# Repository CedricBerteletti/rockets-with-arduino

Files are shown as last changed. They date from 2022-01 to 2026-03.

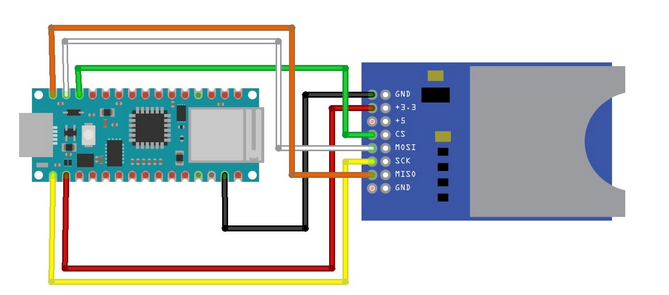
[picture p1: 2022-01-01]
electronique/arduino-sdcard.PNG

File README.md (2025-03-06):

# Fusée avec Arduino embarqué

Quelques programmes pour notre fusée avec Arduino embarqué !

## compte-a-rebours - Compte à rebours

Un compte à rebours simple de 10 secondes, verrouillé par une clé RFID et déclenchant un relais, pour l'allumage électrique d'une micro-fusée.
Basé sur un Arduino Nano.

Bibliothèques nécessaires :
- SPI
- MFRC522 V1.4 : contrôle de la clé RFID

## logiciel-vol - Logiciel de vol pour l'Arduino embarqué

Basé sur un Arduino Nano 33 IoT.

Bibliothèques nécessaires :
- Arduino_LSM6DS3 : centrale inertielle (CI)
- WiFiNINA : connexion et communication via Wifi
- SD : gestion de la carte SD
- Servo : gestion des servomoteurs
- avr/dtostrf : pour convertir les floats en chaîne de caractères

Permet de recevoir via Wifi les commandes (cf. exemple-script-fusee.rl) :
- Commandes générales et connexion :
    - *wifi.connectNetwork ssid pwd*: permet de se connecter au réseau wifi *ssid* avec le mot de passe *pwd*.
    - *wifi.broadcastUdpClient n ip_rocket port_rocket*: permet de connaître le client distant numéro n (de 0 à 4) et de lui retourner les mesures et le statut de la fusée.
    - *system.delay duree* : bloque l'exécution de la boucle principale de l'Arduino pendant *duree* ms.
- Loggers et différents états  :
    - *rocket.status* : état de la fusée.
    - *wifi.status* : état de la connexion Wifi.
    - *logger.status* : indique les différents loggers actifs.
	- *logger.log str* : écrit la chaîne quelconque str dans les logs. Possible d'utiliser des commandes au pré-processeur dans la chaîne (par exemple {{DATE}}).
    - *logger.initSdcard* : initialise et lance les logs sur la carte SD.
    - *logger.flushToSdcard* : force le vidage du cache des logs sur la carte SD.
	- *logger.sizeLogsFile* : taille du fichier de logs
	- *logger.clearLogsFile* : vider le fichier de logs
    - *logger.setSamplesLogImuData n* : indique le *n* nombre d'échantillons sautés pour les logs (via serial, SD-Card et Wifi) des données de la centrale inertielle. 0 => pas de log.
    - *logger.activateLogFlush* et *logger.deactivateLogFlush*: active/désactive les logs de vidage du cache sur la carte SD.
    - *logger.activateLogRocketStatus* et *logger.deactivateLogRocketStatus* : active/désactive les logs d'état général de la fusée.
	- *logger.activateLogToSerial* et *logger.deactivateLogToSerial*
	- *logger.activateLogToSd* et *logger.deactivateLogToSd*
	- *logger.activateLogToWifi* et *logger.deactivateLogToWifi*
- Plan/script de vol de la fusée :
    - *flightplan.configureStep no_step delai commande* : précise la temporisation (durée en ms) de l'étape *no_step* et la commande à exécuter au **début** de l'étape.
    - *flightplan.getSteps* : renvoie toutes les étapes de vol de la fusée.
    - *flightplan.goStep step* : permet de passer directement à l'étape *step* (et éventuellement de faire des boucles).
- Centrale inertielle :
    - *imu.getBuffer* : renvoie toutes les données inertielles contenues dans le buffer de calibration
    - *imu.calibrate ax ay az valpha vbeta vgamma* : intégre des offsets dans les données brutes des capteurs de façon à avoir exactement les valeurs passées en calibration
    - *imu.setMinAccelerationFilter mina" : paramètre l'accélération minimale à prendre en compte dans la centrale inertielle (les accélérations inférieures seront considérées comme nulles pour éviter la dérive)
    - *imu.setMinAngularVelocityFilter minv" : paramètre la vitesse angulaire minimale à prendre en compte dans la centrale inertielle (les accélérations inférieures seront considérées comme nulles pour éviter la dérive)
    - *imu.setRcsServoX n* : indique que le servo-moteur n servira pour le contrôle de l'axe X par la tuyère orientable
    - *imu.setRcsServoY n* : indique que le servo-moteur n servira pour le contrôle de l'axe Y par la tuyère orientable
    - *imu.setWcsServoX n* : indique que le servo-moteur n servira pour le contrôle de l'axe X par les ailerons
    - *imu.setWcsServoY n* : indique que le servo-moteur n servira pour le contrôle de l'axe Y par les ailerons
    - *imu.activateRcs* et *imu.deactivateRcs* : active et désactive la stabilisation par la tuyère orientable
    - *imu.activateWcs* et *imu.deactivateWcs* : active et désactive la stabilisation par les ailerons    - 
    - *imu.setCorrectionFunctionParameters a b c d*: Passage des paramètres d'un polynome de degré 3 (a.err³ + b.err² + c.err + d) donnant la correction à appliquer sur la position des servomoteurs en fonction de l'écart à la verticale.
- Lancement et actions générales :
    - *rocket.launch code* ou *flightplan.start code* : Lance l'exécution du plan de vol avec le lancement de l'étape 0. Protégé par un code.
    - *rocket.stage* : Sans effet. Permet de générer un log indiquant que l'on est passé à l'étage suivant de la fusée.
    - *flightplan.stop code* : interrompt le programme de la fusée et revient à l'étape initiale. Protégé par un code. Attention aux conséquences !
- Gestion des signaux sur les broches de l'Arduino :
    - *pin.setMode pin mode* : configure la broche n°*pin* (OUTPUT/INPUT). 
    - *pin.digitalWrite pin niveau* : envoie un signal (0 ou 1) ou l'arrête sur la sortie numérique *pin* désignée.
    - *pin.fire pin* : idem *pin.digitalWrite pin 1*.
    - *pin.tone pin freq* : joue un son de fréquence *freq* hz sur la sortie *pin*.
    - *pin.toneStop pin* : coupe le son sur la sortie *pin*.
- Gestion des servo-moteurs
    - *servo.setAngle servo angle* : positionne (mais sans correction/calibration) sur un *angle* précis (de 0 à 180°) le servo moteur n°*servo*.
    - *servo.setPosition servo position* : positionne le servo moteur n°*servo* sur une position repérée de -100 à 100 (en tenant compte de la calibration du servo).
    - *servo.setOffset servo offset* : indique un décalage du 0 pour le servo moteur n°*servo*
    - *servo.setSlope servo slope* : indique le coefficient entre angle et position pour le servo moteur n°*servo*
    - *servo.status servo* : indique le status pour le servo moteur n°*servo* (paramètres de calibration et consigne actuelle)

Remarques sur l'Arduino Nano 33 IoT :
- La gestion de l'USB est basé sur un programme chargé par le bootloader. Mais si le programme personnalisé est bogué, il peut empêcher la routine de gestion de l'USB de fonctionner. L'Arduino apparaît alors "briqué". Il faut appuyer rapidement 2 fois sur le boutons reset pour forcer le rechargement du bootloader (et la gestion du port USB).
- **Attention** : I/O en 3,3 V.

Remarques sur la carte SD :
- à alimenter en 5V ;
- nom de fichier de 8 caractères maximum (retour à l'époque du DOS !!)

Commandes lancées depuis un smartphone :
- Trouver l'adresse IP de la fusée :
```
ip neigh
```
- Connexion à la fusée (port 23900 par défaut) :
```
nc -u 192.168.x.x {port}
```
Il est ensuite possible de continuer à taper pour envoyer les commandes.
- Etat de la connexion :
```
netstat | grep {port}
```
- Envoi d'une commande :
```
echo -n "WB 0 192.168.0.3 23900" > /dev/udp/192.168.0.3/23900
```

## controle-sol - Centre de Contrôle et de Télémétrie

Application Python permettant de configurer le vol de la fusée, de vérifier son statut, de lancer le compte à rebours final et d'acquérir et d'afficher les infos de vol.

## Électronique

- Possibilité d'alimenter les servo-moteurs à une tension supérieure aux 5V de l'Arduino (par exemple avec les 7,4 V de la batterie), pour accélérer la vitesse de rotation.

### Arduino Nano 33 IoT

Ne pas utiliser les broches D10, D11, D12, D18 et D19 utilisées par défaut pour les interfaces SPI et I2C (sur laquelle est branchée notamment l'IMU).

#### LSM6DS3 intégré

The Arduino LSM6DS3 library allows us to use the Arduino Nano 33 IoT IMU module without having to go into complicated programming. The library takes care of the sensor initialization and sets its values as follows:
- Accelerometer range is set at -4 |+4 g with -/+0.122 mg resolution.
- Gyroscope range is set at -2000 | +2000 dps with +/-70 mdps resolution.
- Output data rate is fixed at 104 Hz.

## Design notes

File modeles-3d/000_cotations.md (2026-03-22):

## Quelques dimensions standards

- Diam engrenage 12 dents : 13.5 mm
- Diam engrenage 20 dents : 21.5 mm
- Diam engrenage 24 dents : 26 mm
- Diam engrenage 32 dents : 37.2 mm
- Entraxe Lego engrenage 12 dents - 12 dents : 12.5 mm
- Entraxe Lego engrenage 12 dents - 20 dents : 16.5 mm
- Entraxe Lego engrenage 12 dents - 20 dents : 18.75 mm
- Entraxe Lego engrenage 12 dents - 20 dents : 24.5 mm
- Engrenage Lego : module 1,0 mm
- Engrenage Servo MG90 / SG90 / AD002 : module 0,20 mm ; 24 dents

## Inserts M2 / M2.5 / M3

Diamètre trou pour insert M2 : 3,2 mm
Diamètre trou pour vis M2 : 2,0 mm
Diamètre trou pour insert M3 : 4,0 mm
Diamètre trou pour vis M3 : 3,0 mm

## Dimensionnement des parachutes

- 125 cm : 600 - 1400 g
- 90 cm : 400 - 600 g
- 70cm : 300 - 400 g
- 55 cm : 200 - 300 g
- 45 cm : 100 - 200 g
- 35 cm : 50 - 100 g

# Fusée étage 2 seul

## Base

Hauteur : 185 mm
Masse sans moteur : 180 g
Centre de gavrité (depuis bas) : 80 mm

## Corps

Hauteur : 585 mm
Masse : 146 g
Centre de gavrité (depuis bas) : 315 mm

## Base + Corps

Hauteur : 770 mm
Masse sans moteur : 326 g
Centre de gavrité (depuis bas) : 275 mm

## Coiffe

Hauteur : 210 mm
Masse sans batterie : 228 g
Centre de gavrité (depuis bas) : 65 mm
Masse batterie Black Lithium 45 C 7,4V 300mAh : 16 g

## Caméra

Environ 1 Go pour 4 min d'enregistrement

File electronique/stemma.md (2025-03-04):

STEMMA 4-Pin I2C (both standard & STEMMA QT)

This connector is for I2C devices and has a 4 pin connector

For JST PH (2mm pitch) the pin order is

    Green for SCL
    White for SDA
    Red for V+
    Black for GND

For the STEMMA QT cables, we follow the Qwiic convention:

    Black for GND
    Red for V+
    Blue for SDA
    Yellow for SCL

Note the colors are slightly different for SDA/SCL but the pin order is the same

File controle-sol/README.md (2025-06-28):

# Logiciel de contrôle au sol

## Description

## Lancement

### Windows
Au besoin, créer le Python virtual environment and installer les différents packages.
```
python.exe -m pip install --upgrade pip
python -m venv .venv
.\.venv\Scripts\activate
pip install PyQt6
pip install pyqtgraph
pip install PyOpenGL
pip install numpy-stl
```

Activer le Python virtual environment
```
.\.venv\Scripts\activate
```

Lancement
```
python main.py
```

### Linux
Au besoin, créer le Python virtual environment and installer les différents packages.
```
python3 -m venv .venv
source .venv/bin/activate
pip3 install PyQt6
pip3 install pyqtgraph
pip3 install PyOpenGL
pip3 install numpy-stl
```

Activer le Python virtual environment
```
source .venv/bin/activate
```

Lancement
```
python3 main.py
```

## TODO

- EcranPrincipal : signals pour le bouton Connecter !
- EcranPrincipal : signals pour les boutons Lancer et Stop ! Ouvrir une boîte de dialogue pour le mot de passe (précharger avec self.password).
- EcranPrincipal : Ajouter splitter entre les deux groupes de widgets graphiques du panneau droit
- EcranPrincipal : toggle de défilement auto pour les logs généraux du panneau gauche (cf. panneau droit)
- CentraleInertielle : intégrations vitesses et positions (en supposant le référentiel galiléen pour l'instant)
- Orienter la vue 3D en fonction de l'orientation réelle de la fusée
- Instructions RFP supplémentaires destinées au centre de contrôle pour indiquer les fichiers 3D lors des différents étages.

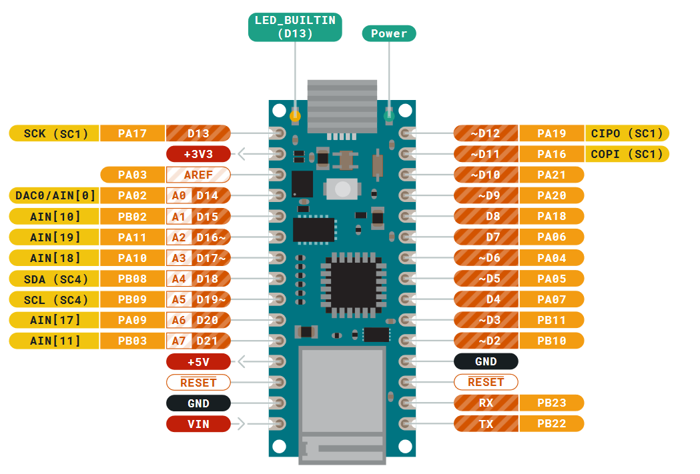
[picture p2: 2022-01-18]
electronique/arduino-pins2-correct-numero-pin.PNG

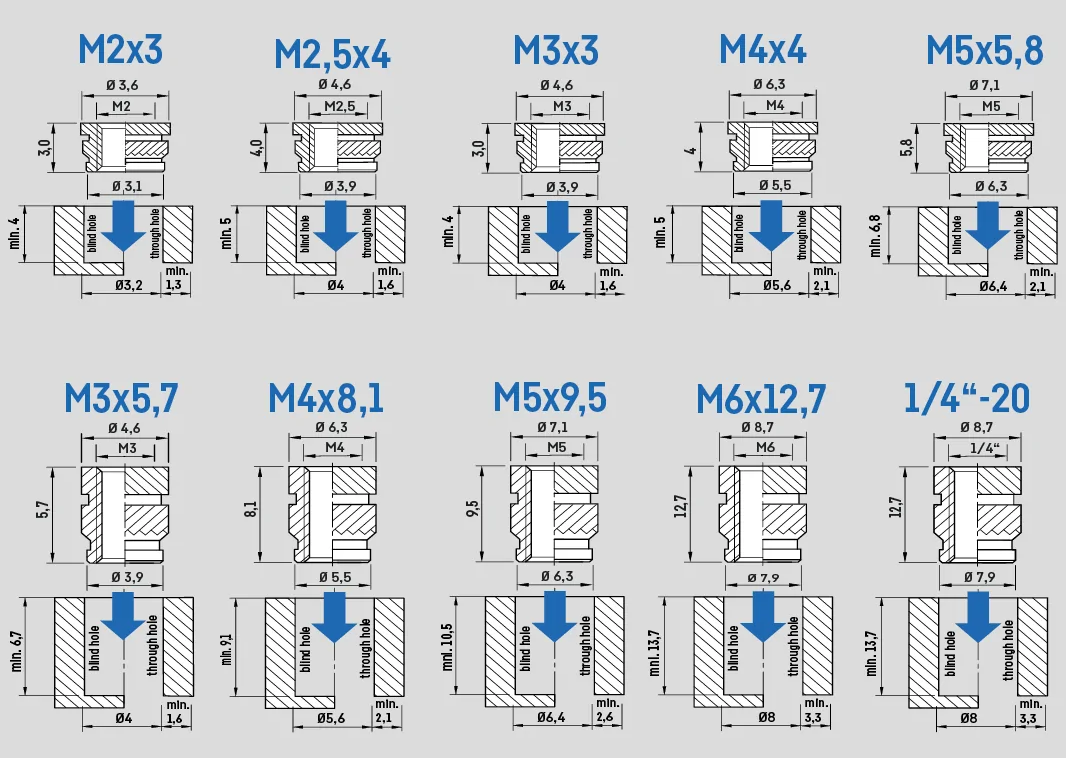
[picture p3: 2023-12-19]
modeles-3d/000_cotations_inserts.png

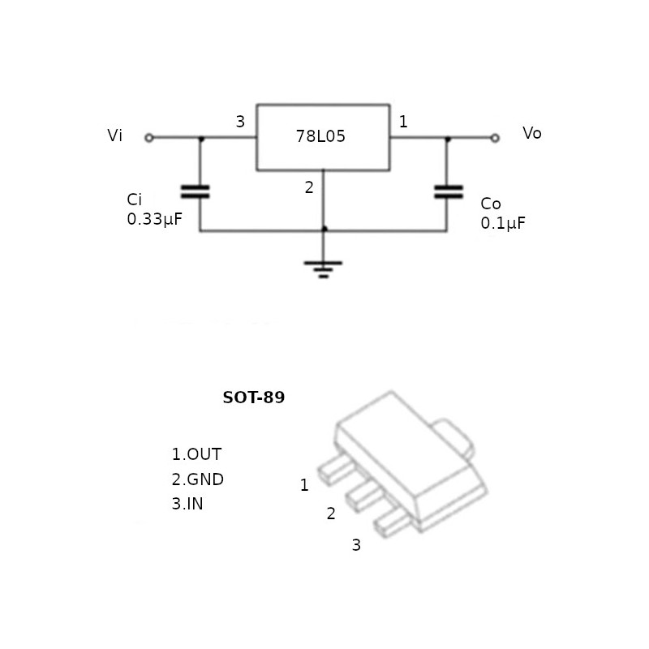
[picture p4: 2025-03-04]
electronique/regulateur-de-tension-5v-avec-perte-7805.jpg

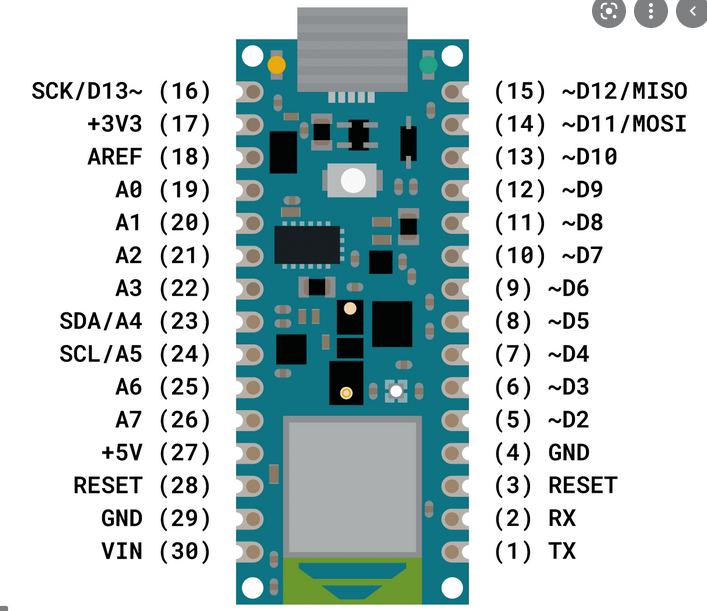
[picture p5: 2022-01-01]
electronique/arduino-pins.PNG

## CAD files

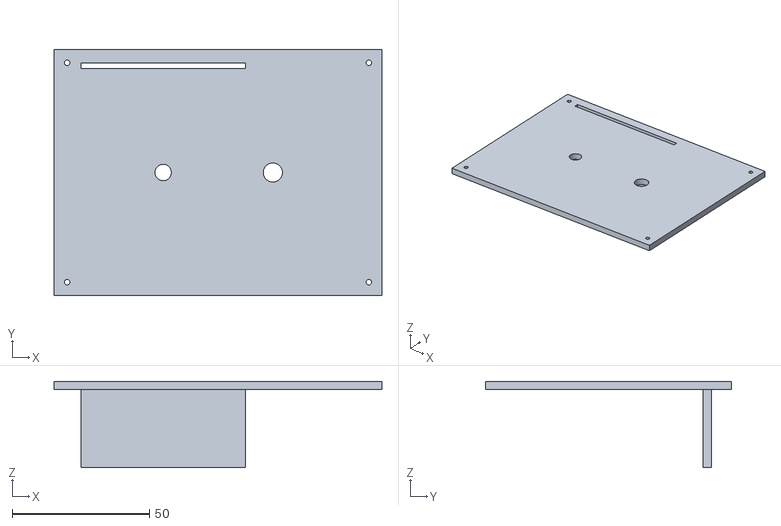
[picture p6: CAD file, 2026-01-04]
compte-a-rebours/modeles-3d/couvercle.stl
119.6 x 89.6 x 31.5

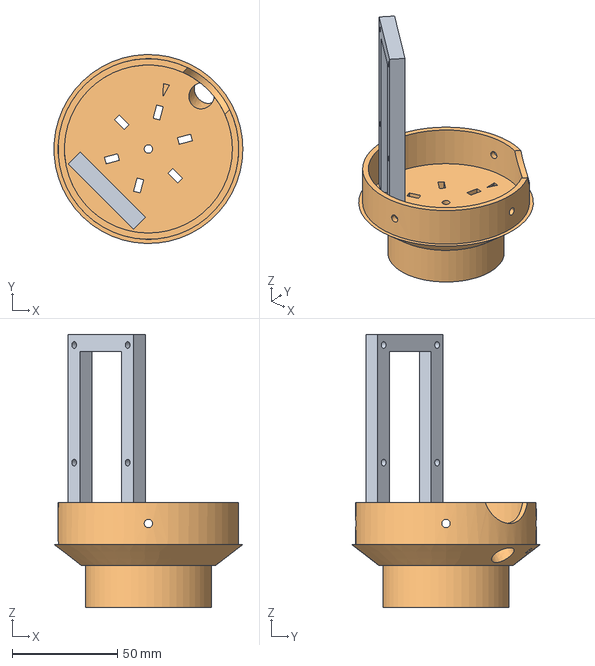
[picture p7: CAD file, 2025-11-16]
modeles-3d/250_etage2b_base_coiffe.FCStd
89.9 x 90.0 x 130.0 mm
Support Arduino
Corps

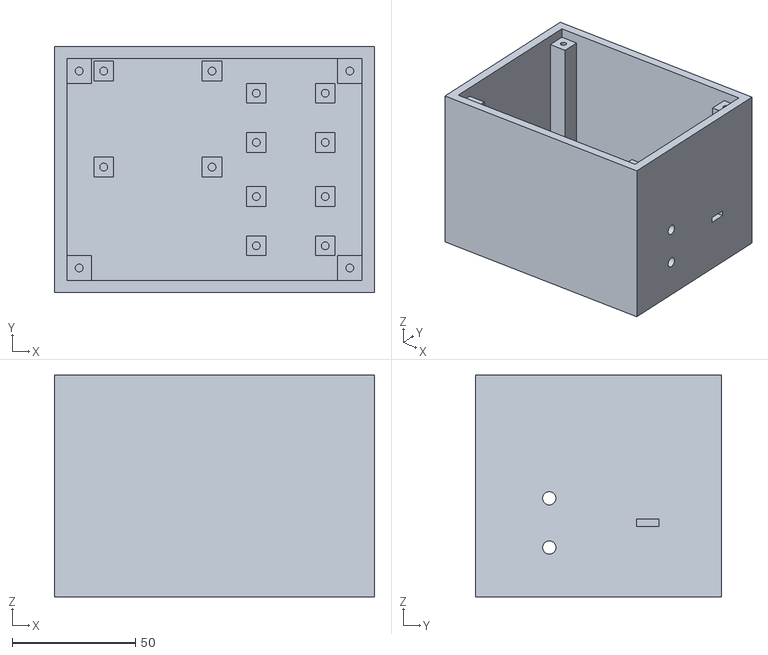
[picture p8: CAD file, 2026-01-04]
compte-a-rebours/modeles-3d/boitier.stl
130.0 x 100.0 x 90.0

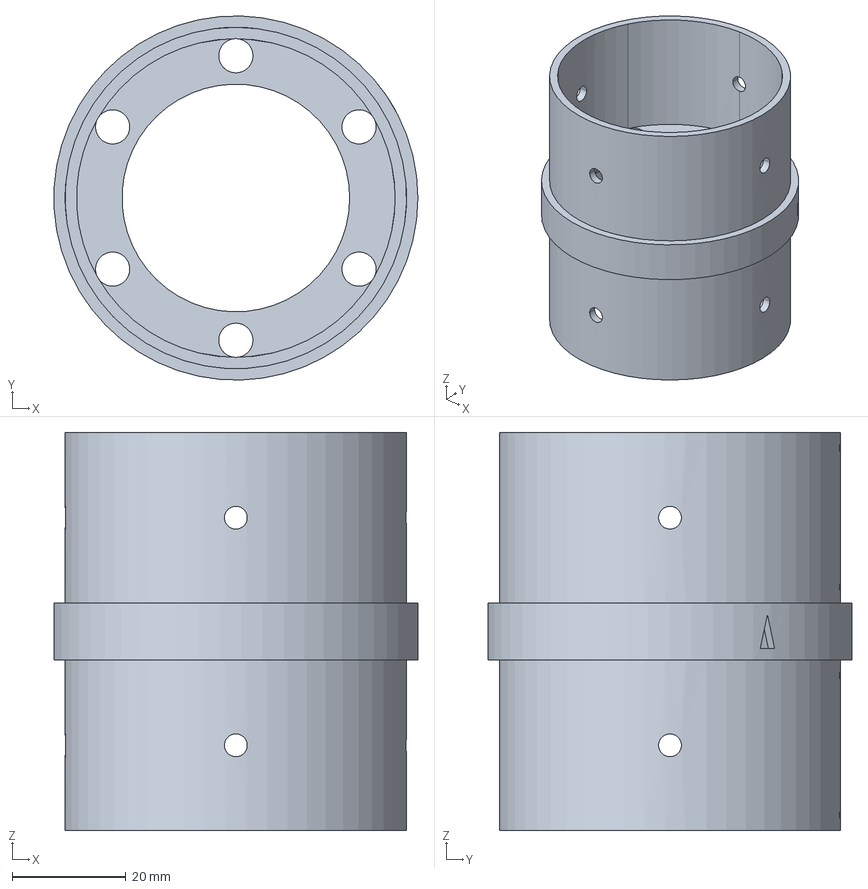
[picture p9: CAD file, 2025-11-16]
modeles-3d/210_etage2_liaison.FCStd
63.9 x 64.0 x 70.0 mm

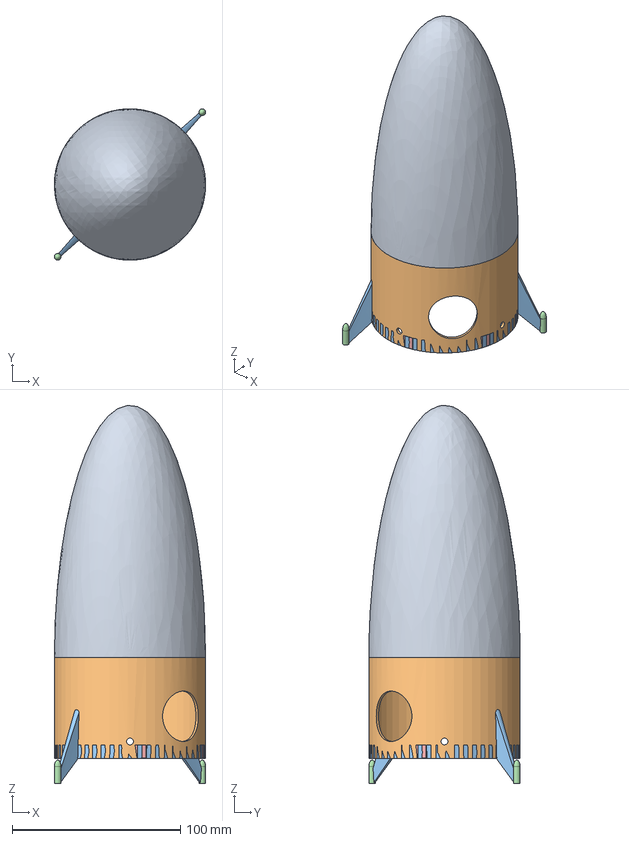
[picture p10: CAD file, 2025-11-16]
modeles-3d/251_etage2b_coiffe.FCStd
90.0 x 90.0 x 224.9 mm
Coiffe
Corps
Ailerons
Corps001
Tube porte ailerons

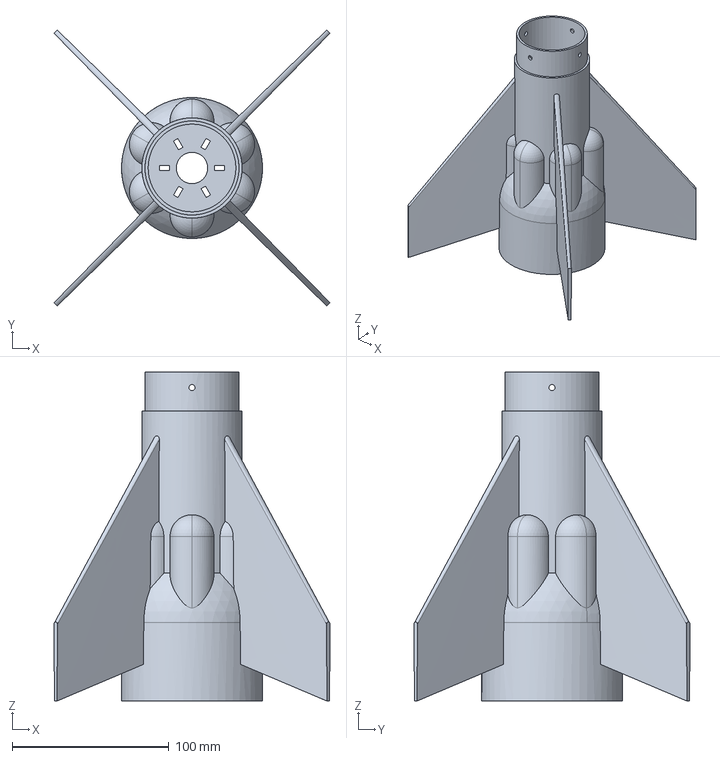
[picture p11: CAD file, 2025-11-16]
modeles-3d/200_etage2_base.FCStd
176.1 x 176.1 x 210.0 mm

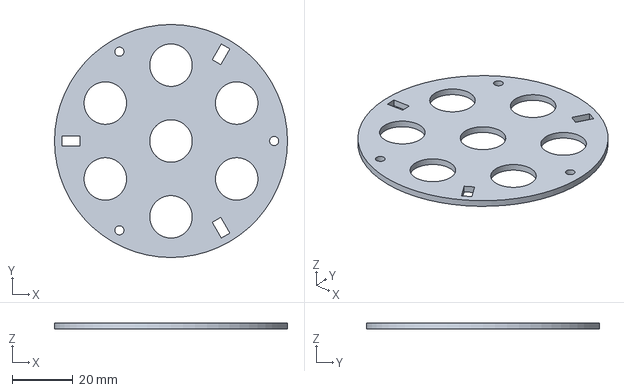
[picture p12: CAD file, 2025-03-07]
modeles-3d/701_moteur_berceau_7_couvercle.FCStd
76.8 x 76.8 x 2.00 mm

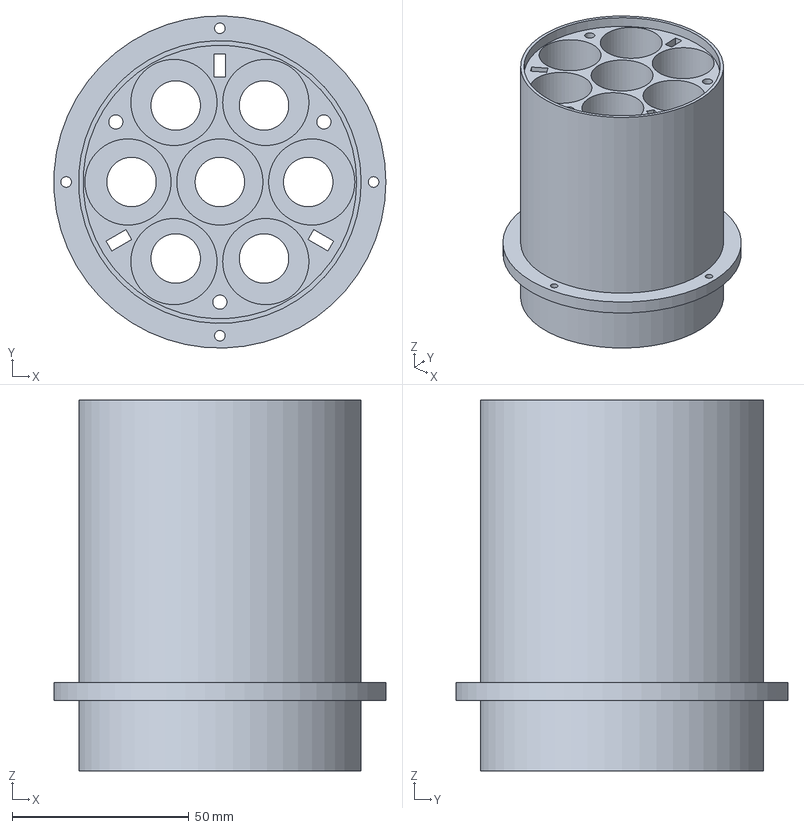
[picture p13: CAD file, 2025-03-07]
modeles-3d/700_moteur_berceau_7.FCStd
93.9 x 94.0 x 105.0 mm

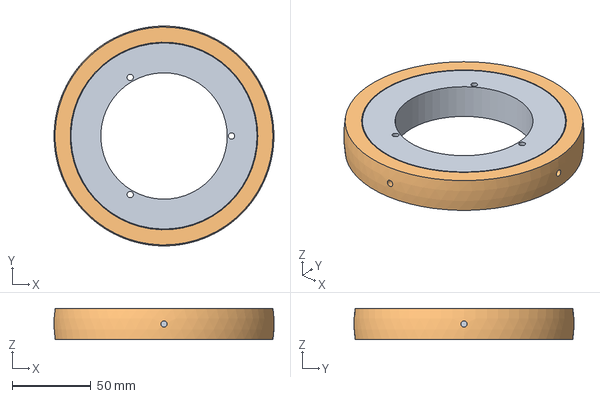
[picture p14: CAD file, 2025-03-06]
modeles-3d/720_orientation_moteurs_sphere.FCStd
139.9 x 139.9 x 20.0 mm
Corps001
Corps

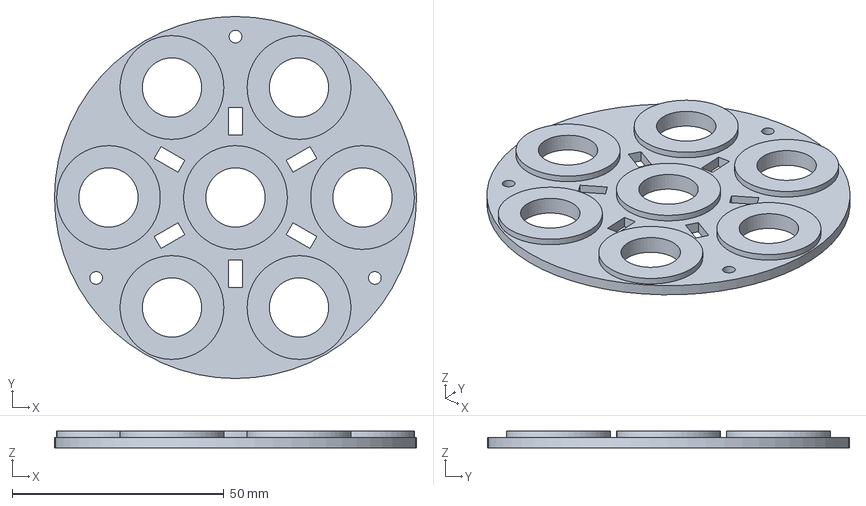
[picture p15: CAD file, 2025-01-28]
modeles-3d/201_etage2_couvercle_base.FCStd
85.5 x 85.5 x 4.00 mm

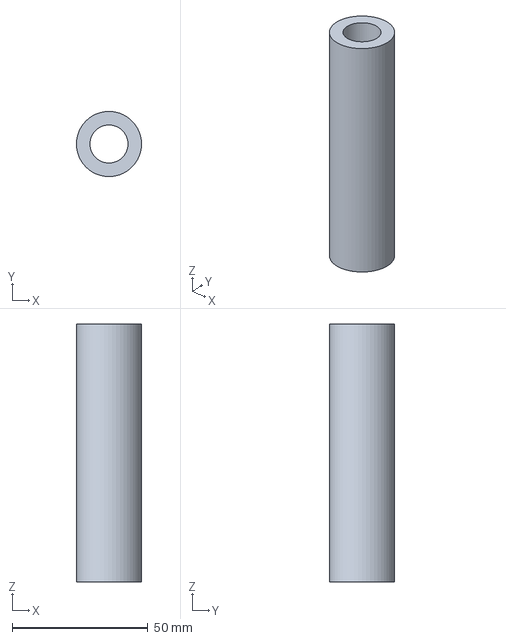
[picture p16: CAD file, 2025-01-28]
modeles-3d/710_adaptateur_moteur_24_95_vers_18_70.FCStd
24.0 x 24.0 x 95.0 mm

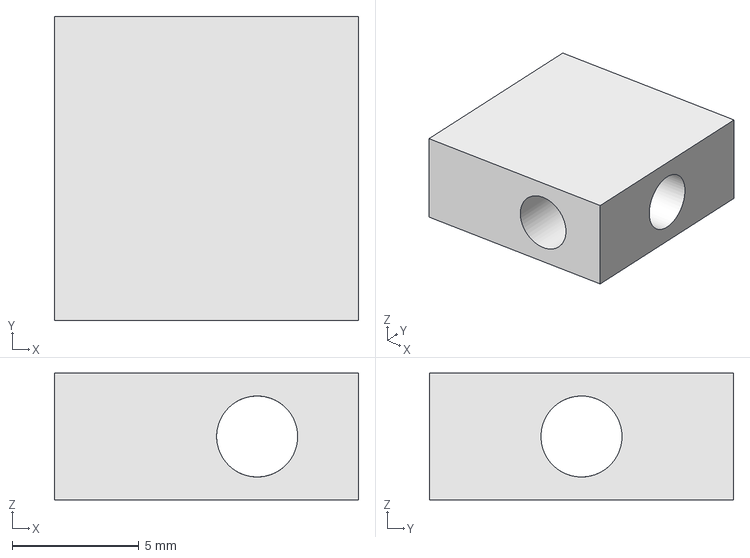
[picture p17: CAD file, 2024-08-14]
modeles-3d/902_servo_fixation.FCStd
12.0 x 12.0 x 5.00 mm

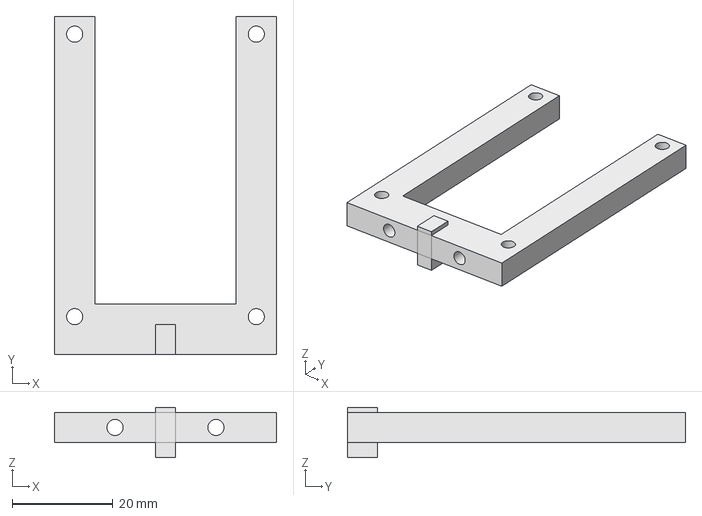
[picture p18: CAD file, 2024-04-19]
modeles-3d/301_capsule_support_arduino.FCStd
44.0 x 67.0 x 10.0 mm

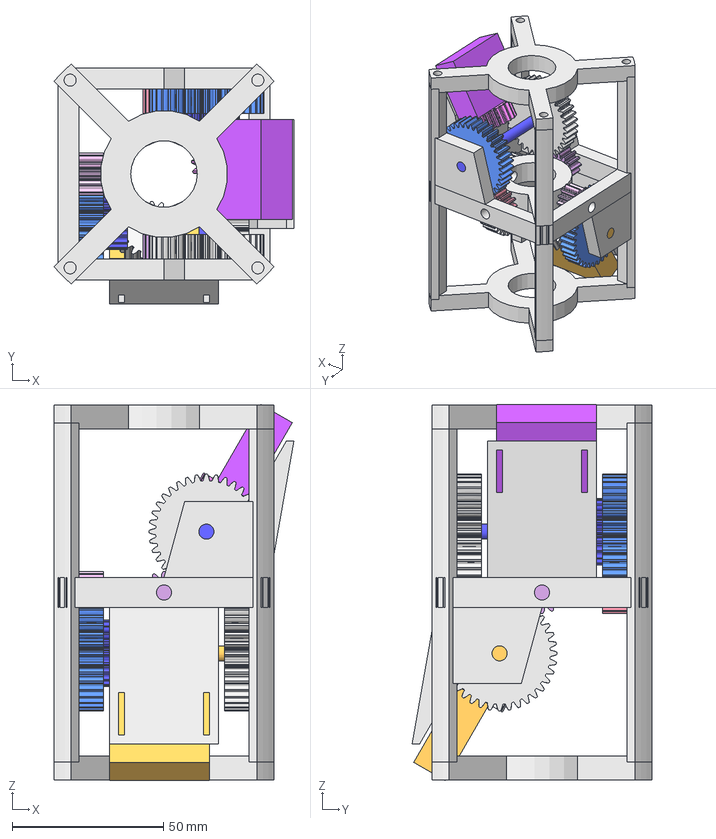
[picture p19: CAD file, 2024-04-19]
modeles-3d/300_capsule_support_engrenages_ailerons.FCStd
79.2 x 79.2 x 124.2 mm
Cadre extérieur
Montant1
Montant2
Montant3
Montant4
Support d'axes 1
Support d'axes 2
Support d'axes 3
Support d'axes 4
Support servo 1
Support servo 2
Cadre intérieur
Guide tube moteur 1
Guide tube moteur 2
EngrenageA1
EngrenageB1
Axe AB1
EngrenageA2
EngrenageB2
EngrenageA3
Servo
EngrenageA4
EngrenageA005
EngrenageB003
EngrenageA006
EngrenageB004
EngrenageA007
Axe AB002
EngrenageA008
Servo002
EngrenageA009

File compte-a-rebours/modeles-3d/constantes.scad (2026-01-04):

hauteur = 90;
longueur = 130;
largeur = 100;
epaisseur = 5;
jeu = 0.2;

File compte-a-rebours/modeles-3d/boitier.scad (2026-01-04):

use <commun.scad>

include <constantes.scad>

module boitier() {
    union() {
        // Boitier externe
        difference() {
            cube([longueur, largeur, hauteur], center = true);
            union() {
                translate ([0, 0, epaisseur]) cube([longueur-2*epaisseur, largeur-2*epaisseur, hauteur-epaisseur], center = true);
                
                // Trous douilles
                translate([0, -largeur/5, -hauteur/2+20])
                rotate([0, 90, 0])
                cylinder(h=longueur+jeu, r1=2.5+jeu, r2=2.5+jeu, center=true, $fn=30);
                translate([0, -largeur/5, -hauteur/2+40])
                rotate([0, 90, 0])
                cylinder(h=longueur+jeu, r1=2.5+jeu, r2=2.5+jeu, center=true, $fn=30);
                
                
                translate([longueur/2, largeur/5, -hauteur/6])
                cube([longueur/2+jeu, 9, 3], center=true);
            }
        }
        
        // Fixation couvercle
        translate ([longueur/2-2*epaisseur, largeur/2-2*epaisseur, 0]) fixation_couvercle();
        translate ([-longueur/2+2*epaisseur, largeur/2-2*epaisseur, 0]) fixation_couvercle();
        translate ([longueur/2-2*epaisseur, -largeur/2+2*epaisseur, 0]) fixation_couvercle();
        translate ([-longueur/2+2*epaisseur, -largeur/2+2*epaisseur, 0]) fixation_couvercle();
        
        // Support circuit imprimé
        translate([-longueur/2+44/2+epaisseur+18, largeur/2-39/2-epaisseur-8, -hauteur/2+epaisseur+4]) pieds_support_rect(44, 39, 10, 8);
        
        relai_trans_x = longueur/2-28/2-epaisseur-15;
        relai_trans_y = largeur/2-20/2-epaisseur-14;
        relai_trans_z = -hauteur/2+epaisseur+15;
        // Relai commande fusée
        translate([relai_trans_x, relai_trans_y, relai_trans_z]) relai_arduino_support(30);
        
        // Relai commande allumage
        translate([relai_trans_x, -relai_trans_y, relai_trans_z+10]) relai_arduino_support(50);
        
        // Relai puissance allumage
    }
}

module fixation_couvercle() {
    difference () {
        translate ([0, 0, -epaisseur/2-jeu/2]) cube([2*epaisseur, 2*epaisseur, hauteur-epaisseur-jeu], center = true);
        translate ([0, 0, hauteur/2-10]) m2_trou_insert();
    }
}

boitier();

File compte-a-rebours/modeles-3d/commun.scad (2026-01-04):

jeu = 0.2;

module m2_trou_vis(hauteur=10) {
    cylinder(h=hauteur, r1=1, r2=1, center=true, $fn=30);
}

module m2_trou_insert(hauteur=10) {
    cylinder(h=hauteur, r1=1.6, r2=1.6, center=true, $fn=30);
}

module m3_trou_vis(hauteur=10) {
    cylinder(h=hauteur, r1=1.5, r2=1.5, center=true, $fn=30);
}

module m3_trou_insert(hauteur=10) {
    cylinder(h=hauteur, r1=2, r2=2, center=true, $fn=30);
}

module relai_arduino_support(hauteur=10) {
    pieds_support_rect(28, 20, hauteur, 8);
}

module pieds_support_rect(longueur=28, largeur=20, hauteur=10, profondeur_trou=10) {
    // La longueur et la largeur correspondent aux entre-axes des trous
    // de fixation
    translate([-longueur/2, -largeur/2, 0]) pied(hauteur, profondeur_trou);
    translate([-longueur/2, largeur/2, 0]) pied(hauteur, profondeur_trou);
    translate([longueur/2, -largeur/2, 0]) pied(hauteur, profondeur_trou);
    translate([longueur/2, largeur/2, 0]) pied(hauteur, profondeur_trou);
}

module pied(hauteur=10, profondeur_trou = 10) {
    difference() {
        cube([8, 8, hauteur], center=true);
        translate([0, 0, (hauteur-profondeur_trou)/2]) m2_trou_insert(profondeur_trou+jeu);
    }
}

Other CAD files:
modeles-3d/900_axe_5_mm.FCStd
modeles-3d/302_capsule_aileron.FCStd
modeles-3d/901_servo_engrenage.FCStd
compte-a-rebours/modeles-3d/couvercle.scad
compte-a-rebours/modeles-3d/ensemble.scad
modeles-3d/201_etage2_couvercle_base.stl
modeles-3d/210_etage2_liaison.3mf
modeles-3d/210_etage2_liaison.stl
modeles-3d/250_etage2b_base_coiffe.stl
modeles-3d/251_etage2b_coiffe.stl
modeles-3d/300_capsule_support_engrenages_ailerons.stl
modeles-3d/301_capsule_support_arduino.stl
modeles-3d/302_capsule_aileron.stl
modeles-3d/700_moteur_berceau_7.stl
modeles-3d/701_moteur_berceau_7_couvercle.stl
modeles-3d/710_adaptateur_moteur_24_95_vers_18_70.stl
modeles-3d/720_orientation_moteurs_sphere.stl
modeles-3d/900_axe_5_mm.stl
modeles-3d/901_servo_engrenage.stl
modeles-3d/902_servo_fixation.stl

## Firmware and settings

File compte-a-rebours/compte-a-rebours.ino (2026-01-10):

/*
 * --------------------------------------------------------------------------------------------------------------------
 * Compte à rebours pour l'allumage d'une fusée. Verrouillé par une clé RFID.
 * --------------------------------------------------------------------------------------------------------------------
 * @author Cédric Berteletti
 */

#include <SPI.h>
#include <MFRC522.h>

#define RST_PIN       9     // Configurable, see typical pin layout above
#define SS_PIN        10    // Configurable, see typical pin layout above

#define SEUIL_BOUTON  255
#define ROCKET_PIN    20    // Broche à laquelle est reliée le câble de signal de la fusée contrôlant la mise-à-feu
#define BOUTON_PIN    21    // Broche à laquelle est relié le bouton de lancement

#define COMMANDE_PIN  2     // Broche de commande du relai de mise à feu

// Broches pour la LED RVB
#define ROUGE_PIN     16
#define VERT_PIN      17
#define BLEU_PIN      19


MFRC522 mfrc522(SS_PIN, RST_PIN);   // Création de l'instance pour la gestion de la clé RFID


MFRC522::MIFARE_Key cleRfid;

void setup() {
  Serial.begin(9600);  // Initialisation du port série pour la communication avec le PC
  while (!Serial);     // Ne rien faire si le port série n'est pas ouvert (pour Arduinos basé ATMEGA32U4)
  SPI.begin();         // Initialisation du bus SPI (auquel est relié la carte de lecture RFID)
  mfrc522.PCD_Init();  // Initialisation de la carte de lecture RFID MFRC522
  
  // Prepare key - all keys are set to FFFFFFFFFFFFh at chip delivery from the factory.
  for (byte i = 0; i < 6; i++) {
    cleRfid.keyByte[i] = 0xFF;
  }
  pinMode(ROCKET_PIN, INPUT);
  pinMode(BOUTON_PIN, INPUT);

  pinMode(ROUGE_PIN, OUTPUT);
  pinMode(VERT_PIN, OUTPUT);
  pinMode(BLEU_PIN, OUTPUT);
  analogWrite(ROUGE_PIN, 0);
  analogWrite(VERT_PIN, 0);
  analogWrite(BLEU_PIN, 255);

  pinMode(COMMANDE_PIN, OUTPUT);

  Serial.println(F("Console de lancement en attente ..."));
}

const int STATUT_VERROUILLE = 0;
const int STATUT_DEVERROUILLE = 1;
const int STATUT_COMPTE_A_REBOURS = 2;
const int STATUT_ALLUMAGE = 3;
int statut = STATUT_VERROUILLE;

// Durées en ms
const int DUREE_ALLUMAGE = 4000;
const int DELAI_LECTURE = 100;

const int NB_SECONDES_COMPTE_A_REBOURS_MANUEL = 10;

int intensiteRouge;
int intensiteVert;
int intensiteBleu;


static const char CLE_AUTORISEE[] = "C0 CE 41 25";

// But of course this is a more proper approach
void loop() {
  intensiteRouge = 0;
  intensiteVert = 0;
  intensiteBleu = 0;
  
  if(statut == STATUT_VERROUILLE) {
    intensiteBleu = 255;
    analogWrite(ROUGE_PIN, intensiteRouge);
    analogWrite(VERT_PIN, intensiteVert);
    analogWrite(BLEU_PIN, intensiteBleu);

    // VERIFICATION DE LA CLE RFID
    // Look for new cards, and select one if present
    if ( ! mfrc522.PICC_IsNewCardPresent() || ! mfrc522.PICC_ReadCardSerial() ) {
      delay(50);
      return;
    }  
    // Now a card is selected. The UID and SAK is in mfrc522.uid.
    
    if(verificationCle()) {
      Serial.println("Déverrouillage de la séquence de lancement.");
      statut = STATUT_DEVERROUILLE;

      intensiteVert = 255;
      intensiteBleu = 0;
      
      analogWrite(ROUGE_PIN, intensiteRouge);
      analogWrite(VERT_PIN, intensiteVert);
      analogWrite(BLEU_PIN, intensiteBleu);
    }
    else {    
      Serial.println("ALERTE ! Accès non autorisé !");
            
      intensiteBleu = 0;
      analogWrite(VERT_PIN, intensiteVert);
      analogWrite(BLEU_PIN, intensiteBleu);
      intensiteRouge = 255;
      analogWrite(ROUGE_PIN, intensiteRouge);
      delay(200);
      analogWrite(ROUGE_PIN, 0);
      delay(200);
      analogWrite(ROUGE_PIN, intensiteRouge);
      delay(200);
      analogWrite(ROUGE_PIN, 0);
      delay(200);
      analogWrite(ROUGE_PIN, intensiteRouge);
      delay(200);
      analogWrite(ROUGE_PIN, 0);
    }
  }

  else if(statut == STATUT_DEVERROUILLE && analogRead(BOUTON_PIN) >= SEUIL_BOUTON) {
    Serial.println("Séquence finale");
    statut = STATUT_COMPTE_A_REBOURS;
  }
  else if (statut == STATUT_DEVERROUILLE && analogRead(ROCKET_PIN) >= SEUIL_BOUTON) {
    Serial.println("signal fusée");
    statut = STATUT_ALLUMAGE;
  }
  
  else if (statut == STATUT_COMPTE_A_REBOURS) {

    intensiteVert = 0;
    intensiteVert = 40;
    intensiteRouge = 225;

    bool annulation = false;
    int delai = NB_SECONDES_COMPTE_A_REBOURS_MANUEL; // Compte à rebours en secondes
    while (delai > 0 && !annulation)
    {
      Serial.println(delai);
      analogWrite(ROUGE_PIN, intensiteRouge);
      analogWrite(VERT_PIN, intensiteVert);
      analogWrite(BLEU_PIN, intensiteBleu);
      delay(500);
      analogWrite(ROUGE_PIN, 0);
      analogWrite(VERT_PIN, 0);
      delay(500);

      annulation = analogRead(BOUTON_PIN) >= SEUIL_BOUTON;
      delai--;
    }
    
    if(annulation) {
      Serial.println("Annulation du lancement !");
      statut = STATUT_VERROUILLE;
    }
    else {
      intensiteVert = 0;
      intensiteRouge = 255;
      analogWrite(ROUGE_PIN, intensiteRouge);
      analogWrite(VERT_PIN, intensiteVert);
      analogWrite(BLEU_PIN, intensiteBleu);
      delay(800);
      analogWrite(ROUGE_PIN, 0);
      analogWrite(VERT_PIN, 0);
      delay(200);
      statut = STATUT_ALLUMAGE;
    }
  }
  else if (statut == STATUT_ALLUMAGE) {    
    Serial.println("Décollage !");
    // Mise à feu
    intensiteVert = 0;
    intensiteRouge = 255;
    analogWrite(ROUGE_PIN, intensiteRouge);
    analogWrite(VERT_PIN, intensiteVert);
    analogWrite(BLEU_PIN, intensiteBleu);
    digitalWrite(COMMANDE_PIN, HIGH);
    
    delay(DUREE_ALLUMAGE);
    
    digitalWrite(COMMANDE_PIN, LOW);
    analogWrite(ROUGE_PIN, 0);
    analogWrite(VERT_PIN, 0);
    analogWrite(BLEU_PIN, 0);
    statut = STATUT_VERROUILLE;
  }
  
  delay(DELAI_LECTURE);
}

boolean verificationCle() {
  char cleRfid[20] = "";
  char* pointeurCle = cleRfid;
  char* finBuffer = cleRfid + sizeof(cleRfid);
  for (byte i = 0; i < mfrc522.uid.size; i++) {
      if (pointeurCle + 3 < finBuffer)
      {
          if (i > 0)
          {
              pointeurCle += sprintf(pointeurCle, " ");
          }
          pointeurCle += sprintf(pointeurCle, "%02X", mfrc522.uid.uidByte[i]);
      }
  }
  Serial.print(F("Clé UID:"));
  Serial.print(cleRfid);
  Serial.println();

  if(strcmp(cleRfid, CLE_AUTORISEE) == 0) {
    return true;
  }
  else {    
    return false;
  }
}

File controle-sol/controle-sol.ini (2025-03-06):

[DEFAULT]
logging.level = INFO
theme.main = Fusion

delay.between_commands_ms = 50  # ms

telemetry.debug = false
telemetry.ip = 192.168.0.50
telemetry.port = 23900
telemetry.refresh_delay_ms = 10  # ms
telemetry.integration = true

imu.filters.angular_velocity_min = 1 # en ° par seconde
imu.filters.acceleration_min = 0.1 # en g (gravité terrestre 9.8 m/s²)

graphs.debug = false
graphs.refresh_delay_ms = 100  # ms

visu3d.grid_size = 400
visu3d.camera_distance = 500

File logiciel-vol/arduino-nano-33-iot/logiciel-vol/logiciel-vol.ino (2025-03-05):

/* 
 * --------------------------------------------------------------------------
 * Module principal du programme de vol d'une fusée
 * embarquant un Arduino Nano 33 IoT
 * --------------------------------------------------------------------------
 * @author Cédric Berteletti
 */

#include "constants.h"
#include "aides.hpp"
#include "Logger.hpp"
#include "Wifi.hpp"
#include "CentraleInertielle.hpp"
#include "Servomoteur.hpp"
#include "Interpreteur.hpp"


/* Modules */

// Instanciation d'un loggeur
Logger logger;

// Instanciation d'un objet gérant la connexion et les communications wifi
Wifi wifi;

// Instanciation de l'objet gérant la centrale inertielle (constructeur nécessitant un logger en paramètre)
CentraleInertielle centrale(logger);

// Servomoteurs des ailerons et de la tuyère sur les broches 18 à 21
Servomoteur servos[NB_SERVOS] = {Servomoteur(logger), Servomoteur(logger), Servomoteur(logger), Servomoteur(logger)};
int servosBroches[NB_SERVOS] = {SERVO0_PIN, SERVO1_PIN, SERVO2_PIN, SERVO3_PIN};

/* Programme de vol */
ProgrammeVol programmeVol(logger);

// Instanciation de l'interpréteur de commandes
Interpreteur interpreteur(logger, wifi, centrale, programmeVol, servos);


/* Variable globales */
// Date à laquelle réaliser un nouveau flush des données de logs
// (pas à chaque écriture car prend trop de temps)
long dateFlushSuivant = 0;
// Date à laquelle mettre à jour le statut de la fusée
long dateStatutSuivant = 0;
// Date à laquelle MAJ les données inertielles
long dateLectureImuSuivante = 0;
// Date à laquelle vérifier la présence de nouvelles commandes
long dateLectureCommandeSuivante = 0;
// Chaîne de caractères pour les logs
char strLog[LONGUEUR_MAX_CHAINE_CARACTERES];


/* Initialisation générale de la fusée */
void setup() {
  logger.log(MODULE_SYSTEME, "SYSTEM_INIT", "Initialisation générale");
  initSerie();
  delay(1000);

  logger.initCarteSd();
  
  wifi.listerReseaux();
  wifi.connecter();
  wifi.logStatut();

  logger.wifi = &wifi;
  logger.logUdpActif = true;

  // Pour éviter de polluer les logs, on désactive les logs des données inertielles avant le lancement
  centrale.samplesByDataLog = 0;
  centrale.init();

  // Initialisation des valeurs par défaut de calibration des servo-moteurs
  for(int i=0; i<NB_SERVOS; i++) {
    servos[i].init(i, servosBroches[i]);
  }

  programmeVol.init(millis());
  dateFlushSuivant = programmeVol.dateCourante;
  dateLectureCommandeSuivante = programmeVol.dateCourante;
}


// Boucle principale : lecture des capteurs ou des commandes et actions
void loop() {
  programmeVol.dateCourante = millis();

  // Actions à fréquence réduite (pas effectuées à chaque itération de loop())

  if(programmeVol.dateCourante > dateLectureImuSuivante) {
    centrale.lire();
    centrale.stabiliser();
    dateLectureImuSuivante = programmeVol.dateCourante + DELAI_IMU;
  }

  if(programmeVol.dateCourante > dateLectureCommandeSuivante) {
    interpreteur.lireCommande();
    dateLectureCommandeSuivante = programmeVol.dateCourante + DELAI_COMMANDE;
  }
  
  if(programmeVol.loggingStatutFusee && programmeVol.dateCourante > dateStatutSuivant) {
    programmeVol.logStatutFusee();
    dateStatutSuivant = programmeVol.dateCourante + DELAI_STATUT;
  }
  
  if(programmeVol.dateCourante > dateFlushSuivant) {
    logger.forcerEcritureSurCarteSd();
    dateFlushSuivant = programmeVol.dateCourante + DELAI_FLUSH;
  }

  if(programmeVol.evaluerEtapeSuivante()) {
    interpreteur.verifierEtExecuterCommande(programmeVol.getCommandeCourante());
  }
}

/* Initialisation de la liaison série (pour débogage sur un PC) */
void initSerie() {
  Serial.begin(115200);
  logger.log(MODULE_SYSTEME, "SERIAL_INIT", "Liaison série initialisée");
}

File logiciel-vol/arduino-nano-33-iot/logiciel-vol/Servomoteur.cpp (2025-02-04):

/*
 * --------------------------------------------------------------------------
 * Gestion d'un servomoteur
 * --------------------------------------------------------------------------
 * @author Cédric Berteletti
 */

#include "Servomoteur.hpp"

int positionEnAngle(int position, int offset, float slope) {
  return position*slope + offset;
}

int angleEnPosition(int angle, int offset, float slope) {
  return (angle - offset) / slope;
}


const char Servomoteur::MODULE_SERVO[] = "SERVO";

Servomoteur::Servomoteur(Logger &logger):logger(logger) {
}

void Servomoteur::init(int i, int b) {
  id = i;
  broche = b;
  servo.attach(broche);
  logStatut();
}

void Servomoteur::setDecalage(int d) {
  decalage = d;
}

void Servomoteur::setPente(float p) {
  pente = p;
}

void Servomoteur::angle(int a) {
  servo.write(a);
}

void Servomoteur::position(int p) {
  angle(positionEnAngle(p, decalage, pente));
}

void Servomoteur::logStatut() {
  sprintf(strTmp, "Servo: %i | Angle: %i | Décalage: %i | Pente: %f", id, servo.read(), decalage, pente);
  logger.log(MODULE_SERVO, "STATUT", strTmp);
}

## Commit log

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2021-08-05 Arduino program for a countdown loacked by a RFID key
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2021-12-29 Logiciel de vol : ajout du mode wifi dans le logger
2021-12-29 CCT : début du projet python Centre de Contrôle et de Télémétrie
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2022-01-29 [logiciel-vol] Ajout de la commande pour le buzzer
    [logiciel-vol.ino]
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2022-02-13 [logiciel-vol] Refonte des commandes
    Rationalisation pour limiter les nombres de comparaison de chaînes et d'empilage de variable lorsque la fusée est en cours de vol
2022-02-13 [controle-sol] Début de gestion des données inertielles
    Et adaptation pour la refonte des commandes côté [logiciel-vol]
2022-02-15 [controle-sol] Filtrage des données des gyroscopes pour éviter la dérive
    Egalement correction de la calibration
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2023-03-02 [modeles-3d] Modèle du support d'engrenages des ailerons de la capsule
    [guide_tube.stl, support_engrenages.stl, support_engrenages_ailerons.FCStd]
2023-04-13 [modeles-3d] Modèle du support d'engrenages des ailerons de la capsule
    Correction de quelques côtes
    [guide_tube.stl, support_engrenages_ailerons.FCStd]
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2023-07-22 [modeles-3d] MAJ de la structure porteuse des engrenages de la capsule
    [support_engrenages.stl, support_engrenages_ailerons.FCStd, support_engrenages_ailerons_boolean.FCStd]
2023-07-23 [modeles-3d] Modèle des ailerons de la capsule
    [aileron_capsule.FCStd, aileron_capsule.stl]
2023-09-23 [modeles-3d] MAJ support et aileron supérieur
    [aileron_capsule.FCStd, support_engrenages_ailerons.FCStd, support_engrenages_ailerons_boolean.FCStd]
2023-09-23 [modeles-3d] Engrenage sur le servo-moteur AD002
    [aileron_capsule.stl, engrenage_servo.FCStd, engrenage_servo.stl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]
2023-10-14 [modeles-3d] Ajustement de l'engrenage servo-Lego
    [engrenage_servo.FCStd, engrenage_servo.stl, support_engrenages_ailerons.FCStd]
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2023-11-24 [modeles-3d] MAJ des modèles fusée et aileron supérieur
    [aileron_capsule.stl, capsule_aileron.FCStd, capsule_aileron.stl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]
2023-12-02 [modeles-3d] WIP modèle étage 2 (#3)
    [etage2_base.FCStd]
2023-12-12 [modeles-3d] Modèle base étage 2
    [etage2_base.FCStd, moteur_berceau_7.FCStd, moteur_berceau_7.stl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]
2023-12-16 [modeles-3d] MAJ et ajout bouchon étage 2
    [etage2_base.FCStd, etage2_couvercle_base.FCStd, etage2_couvercle_base.stl]
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2023-12-17 [models-3d] Ajustements dimensions
    [capsule_aileron.stl, capsule_aileron_2.FCStd, etage2_base.FCStd]
2023-12-19 [modeles-3d] MAJ côtes
    [etage2_base.FCStd, etage2_couvercle_base.FCStd, etage2_couvercle_base.stl]
2023-12-29 Refacto IMU
    [servo_engrenage.FCStd]
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2024-01-03 [modeles-3d] MAJ de côtes et pièces d'essai
    [axe_5_mm.FCStd, axe_5_mm.stl, capsule_aileron.FCStd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]
2024-01-03 [logiciel-vol] Correction sur les broches des servo-moteurs
    [logiciel-vol.ino]
2024-01-13 [modeles-3d] Support arduino (#8)
    [capsule_support_arduino.FCStd, capsule_support_arduino.stl]
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2024-02-03 Support arduino dans la capsule
    [capsule_support_arduino.FCStd]
2024-02-03 [modeles-3d] STL du support Arduino
    [capsule_support_arduino.stl]
2024-03-24 [modeles-3d] MAJ côtes et inserts sur différentes pièces
    [capsule_support_arduino.FCStd, capsule_support_arduino.stl, etage2b_liaison.FCStd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]
2024-04-18 [controle-sol] Meilleure gestion du délai de rafraîchissement de la télémétrie pour rendre l'UI plus réactive
2024-04-18 [modeles-3d] Base coiffe lorsque l'étage 2 est tiré seul
    [etage2b_base_coiffe.FCStd, etage2b_base_coiffe.stl]
2024-04-19 [modeles-3d] MAJ modèles 3D
    - Ajustement des trous des inserts M2 et M3
    - Ajout du trou de la caméra (étage 2 tiré seul)
    - Optimisation du modèle OpenRocket de la fusée complète
    [capsule_support_arduino.FCStd, capsule_support_arduino.stl, capsule_support_engrenages.stl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]
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2024-05-18 [modeles-3d] Coiffe étage 2 seul
    [etage2b_coiffe.FCStd, etage2b_coiffe.stl]
2024-05-19 [modeles-3d] Petites corrections de côtes et défauts d'impression
    [etage2_base.FCStd, etage2_couvercle_base.FCStd, etage2_couvercle_base.stl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]
2024-05-20 [modeles-3d] Correction modèle coiffe étage 2B
    [etage2b_coiffe.FCStd, etage2b_coiffe.stl]
2024-05-24 [modeles-3d] Petites améliorations et base coiffe étage 2B
    [etage2_base.FCStd, etage2_couvercle_base.FCStd, etage2_couvercle_base.stl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]
2024-06-08 Qq améliorations mineures
    [etage2b_base_coiffe.FCStd, etage2b_base_coiffe.stl]
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2024-08-14 [modeles-3d] Fixation servo
    [servo_fixation.FCStd, servo_fixation.stl]
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2024-11-17 MAJ modèles 3D passe-fils étage 2
    [etage2_base.FCStd, etage2_couvercle_base.FCStd, etage2_couvercle_base.stl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]
2025-01-26 [modeles-3d] Renommage et préparation passage corps étage 2 à 60 mm
    [200_etage2_base.FCStd, 200_etage2_base.stl, 201_etage2_couvercle_base.FCStd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]
2025-01-27 [modeles-3d] Suite harmonisation étage 2
    Corps de section 60/64 mm et coiffe et base à 90 mm. Baie moteurs pouvant fonctionner avec des moteurs 18-70 mm ou 24-95 mm.
    [200_etage2_base.FCStd, 201_etage2_couvercle_base.FCStd, 201_etage2_couvercle_base.stl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]
2025-01-28 [modeles-3d] Passage à Freecad 1.0
    [200_etage2_base.FCStd, 201_etage2_couvercle_base.FCStd, 201_etage2_couvercle_base.stl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]
2025-01-28 [modeles-3d] Berceau moteur modulaire
    Pour moteurs 24-95 mm ou 18-70 mm.
    [700_moteur_berceau_7.FCStd, 700_moteur_berceau_7.stl, 701_moteur_berceau_7_couvercle.FCStd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]
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2025-03-03 MAJ mineures
    [700_moteur_berceau_7.FCStd, 700_moteur_berceau_7.stl]
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2025-03-06 Fix erreur initialisation IMU et orientation vue 3D
    [CentraleInertielle.hpp, controle-sol.ini]
2025-03-06 [modeles-3d] Prototype orientation moteurs
    [720_orientation_moteurs_sphere.FCStd, 720_orientation_moteurs_sphere.stl]
2025-03-07 [modeles-3d] MAJ du berceau 7 moteurs avec les passe-fils et diverses optimisations de fixation
    [700_moteur_berceau_7.FCStd, 700_moteur_berceau_7.stl, 701_moteur_berceau_7_couvercle.FCStd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]
2025-06-28 MAJ doc et essai PrusaSlicer
    [210_etage2_liaison.3mf]
2025-11-16 MAJ modèles 3D étage 2 seul
    [200_etage2_base.FCStd, 210_etage2_liaison.FCStd, 210_etage2_liaison.stl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]
2025-12-13 Correction programme de vol
2026-01-04 Modèles 3D boitier d'allumage
    [boitier.scad, boitier.stl, commun.scad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]
